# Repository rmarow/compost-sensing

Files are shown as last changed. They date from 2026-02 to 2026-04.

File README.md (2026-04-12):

# Farm Monitoring - Compost Sensing System - Complete Setup Guide
## Milk and Honey Farm at Boulder JCC

**Compost monitoring with waterproof temperature probes, ambient sensors, web dashboard, and email alerts.**

---

## 🎯 What This System Does

### Monitors Your Compost
- **DS18B20 Waterproof Probes**: Measure temperature INSIDE the compost pile
- **Automatic Alerts**: Get email when temps are too high/low
- **Web Dashboard**: View real-time data and 24-hour trends from any device
- **Data Logging**: Everything stored locally in SQLite database

### Your Alert Thresholds
- 🔥 **Compost too hot**: > 65°C (149°F)
- ❄️ **Compost too cold**: < 40°C (104°F)

---

## 📦 Requirements

### Hardware
- **Raspberry Pi 5** (with Raspberry Pi OS)
- **DS18B20 Waterproof Temperature Probes** (stainless steel, goes IN compost)
- **4.7kΩ Resistor** (required for DS18B20)
- **Screw terminal breakout board** and power supply

### Software Files

**Documentation:**
- `README.md` (this file) - Complete setup guide
- `WIRING_GUIDE.md` - Detailed sensor wiring diagrams
- `ALERT_SETUP_GUIDE.md` - Email setup instructions

**Configuration:**
- `config.py` - All settings (thresholds, GPIO pins, alerts)
- `config_local.py` - Local credentials (gitignored, not committed)
- `requirements.txt` - Python dependencies

**Core System:**
- `sensor_test.py` - Test sensors
- `database_setup.py` - Create SQLite database
- `data_collector.py` - Main monitoring script
- `dashboard.py` - Web dashboard server
- `notifications.py` - Email alert handler

**Web Interface:**
- `templates/dashboard.html` - Dashboard UI

---

## 🖨️ 3D Printed Weatherproof Case

A custom case was designed and 3D printed to house the Raspberry Pi on the compost bin. STL files are included in the `/case` folder of this repo.

### Case Features
- **Weatherproof body** — fully enclosed with a snap-on front lid; seal with silicone RTV after assembly
- **Integrated bin hook** — one-piece design, the top wall extends backward to form an arm + lip that slides over the cap board of the bin wall from the inside
- **Power hole** — top-right corner of the case (USB-C cable routes up and away)
- **Sensor holes** — two 6mm holes on the bottom wall so DS18B20 probe cables drop straight down into the compost
- **Labyrinth vents** — zigzag slots on both side walls allow airflow for passive cooling without letting water in
- **Pi standoffs** — four interior nubs match the Raspberry Pi 4 mounting hole pattern; Pi sits flush against the back wall

### Files
case-specs/case.stl                   ← main body (
case-specs/lid.stl                    ← snap-on front panel 

--- 

## 🚀 Quick Start (7 Steps)

### Step 1: Wire Your Sensors

**Read WIRING_GUIDE.md for detailed diagrams!**

**DS18B20 (Waterproof - goes IN compost):**
Note: There are 2 of these, but they share the exact same wiring config. A screw terminal breakout board is how they are attached to the Pi.
```
RED wire    → Pin 1 (3.3V)
YELLOW wire → Pin 7 (GPIO 4)
BLACK wire  → Pin 9 (Ground)
+ 4.7kΩ resistor between RED and YELLOW
```

### Step 2: Clone Repo to Raspberry Pi

```bash
# SSH into your Pi, then:
cd ~
git clone https://github.com/rmarow/compost-sensing.git
cd compost-sensing
```

Note: Instructions for connecting a Raspberry Pi to a monitor, WiFi, keyboard, and mouse can be found in the official Raspberry Pi documentation.

### Step 3: SSH and Enable 1-Wire

```bash
ssh rmarowitz@raspberrypi.local

# Enable 1-Wire interface (required for DS18B20)
sudo raspi-config
# Navigate: Interface Options → 1-Wire → Enable

# Reboot
sudo reboot
```

### Step 4: Install Dependencies

```bash
ssh rmarowitz@raspberrypi.local
cd ~/compost-sensing

# Create virtual environment
python3 -m venv venv
source venv/bin/activate

# Install packages
pip install -r requirements.txt
```

### Step 5: Test Your Sensors

```bash
python sensor_test.py
```

**You should see:**
```
✅ Found 2 DS18B20 sensor(s):
  Sensor 1 (1ft deep):  28-0000005fe1bf - Reading: 55.2°C / 131.4°F
  Sensor 2 (2ft deep):  28-0000005f6979 - Reading: 57.8°C / 136.0°F
```

**If sensors fail**, check WIRING_GUIDE.md troubleshooting section.

### Step 6: Initialize Database

```bash
python database_setup.py
```

Creates database with tables for sensor readings, alerts, and system status.

### Step 7: Start Monitoring!

**Terminal 1 - Data Collector:**
```bash
cd ~/compost-sensing
source venv/bin/activate
python data_collector.py
```

**Terminal 2 - Dashboard:**
```bash
cd ~/compost-sensing
source venv/bin/activate
python dashboard.py
```

**Access Dashboard:**
Open browser and go to: **http://raspberrypi.local:5000**

🎉 **You should see your dashboard with live sensor data!**

---

## 🔧 Configuration

Edit `config.py` to customize your system:

### Temperature Thresholds (Compost)

```python
# DS18B20 waterproof probes inside compost
DS18B20_TEMP_HIGH_THRESHOLD = 65  # Alert if > 65°C (149°F)
DS18B20_TEMP_LOW_THRESHOLD = 40   # Alert if < 40°C (104°F)
```

**Understanding Compost Temps:**
- **< 40°C**: Not actively composting
- **40-55°C**: Active mesophilic phase
- **55-65°C**: Optimal thermophilic phase (BEST!)
- **> 65°C**: Too hot, may kill beneficial bacteria

### Humidity Thresholds (Ambient)

```python
# DHT11 ambient sensor outside bin (currently disabled)
DHT11_HUMIDITY_LOW_THRESHOLD = 40   # Alert if < 40%
DHT11_HUMIDITY_HIGH_THRESHOLD = 70  # Alert if > 70%
```

### Reading Interval

```python
READING_INTERVAL = 1800  # 30 minutes (changeable in config.py)
```

### Dashboard Settings

```python
DASHBOARD_REFRESH = 60  # Auto-refresh every 60 seconds
```

---

## 🔔 Email Alerts (Optional)

Get notified immediately when thresholds are violated.

### Quick Setup

**1. Enable Email Alerts (FREE):**
```python
# In config_local.py (never committed to git)
EMAIL_ALERTS_ENABLED = True
SMTP_USERNAME = "your-email@gmail.com"
SMTP_PASSWORD = "your-gmail-app-password"  # See ALERT_SETUP_GUIDE.md
ALERT_RECIPIENTS = ["farmerbecca@boulderjcc.org"]
```

**2. Test Notifications:**
```bash
python notifications.py
```

**For complete setup instructions, see ALERT_SETUP_GUIDE.md**

### What Alerts Look Like

**Email:**
```
Subject: 🚨 Compost Alert: Bin 1 - 2ft Deep

Alert: Temperature too high: 68.5°C
Threshold: 65°C
Time: 2026-02-15 2:30 PM

[View Dashboard Button]
```

Won't spam you - 1 hour cooldown between duplicate alerts.

---

## 🤖 Run Automatically on Boot

Make the system start when your Raspberry Pi boots.

### Create systemd Services

**1. Data Collector Service:**
```bash
sudo nano /etc/systemd/system/compost-collector.service
```

Paste:
```ini
[Unit]
Description=Compost Sensing Data Collector
After=network.target

[Service]
Type=simple
User=rmarowitz
WorkingDirectory=/home/rmarowitz/compost-sensing
ExecStart=/home/rmarowitz/compost-sensing/venv/bin/python /home/rmarowitz/compost-sensing/data_collector.py
Restart=always
RestartSec=10

[Install]
WantedBy=multi-user.target
```

**2. Dashboard Service:**
```bash
sudo nano /etc/systemd/system/compost-dashboard.service
```

Paste:
```ini
[Unit]
Description=Compost Sensing Dashboard
After=network.target compost-collector.service

[Service]
Type=simple
User=rmarowitz
WorkingDirectory=/home/rmarowitz/compost-sensing
ExecStart=/home/rmarowitz/compost-sensing/venv/bin/python /home/rmarowitz/compost-sensing/dashboard.py
Restart=always
RestartSec=10

[Install]
WantedBy=multi-user.target
```

**3. Enable and Start:**
```bash
sudo systemctl daemon-reload
sudo systemctl enable compost-collector.service
sudo systemctl enable compost-dashboard.service
sudo systemctl start compost-collector.service
sudo systemctl start compost-dashboard.service
```

**4. Check Status:**
```bash
sudo systemctl status compost-collector.service
sudo systemctl status compost-dashboard.service
```

**Now it runs automatically on boot!** ✅

---

## 📊 Using the Dashboard

### What You'll See

**Main Stats Cards:**
- Active alerts (color-coded)
- Number of active sensors
- Last Google Sheets sync (if enabled)

**For Each Sensor:**
- Current temperature in °F (color-coded: green=good, red=alert)
- Temperature in °C (secondary)
- Last reading timestamp

**Combined Temperature Chart:**
- 24-hour trend for both probes on one chart
- 1ft probe in red, 2ft probe in green

**Active Alerts Section:**
- Lists all unacknowledged alerts
- Shows when alert occurred and what threshold was violated

### Accessing Dashboard

**On farm WiFi:**
```
http://raspberrypi.local:5000
```

**By IP address:**
```bash
# Find your Pi's IP
hostname -I
# Then visit: http://192.168.1.XX:5000
```

Works on any device on the same WiFi network!

---

## 🚀 Expanding Your System

### Add More DS18B20 Probes (Easy!)

Monitor multiple depths in the same bin — ALL on the same GPIO 4 pin!

```python
# In config.py
DS18B20_LOCATIONS = [
    {"id": "probe_1ft", "name": "Bin 1 - 1ft Deep", "device_id": "28-0000005fe1bf", "enabled": True},
    {"id": "probe_2ft", "name": "Bin 1 - 2ft Deep", "device_id": "28-0000005f6979", "enabled": True},
]
```

Wire them all the same way — the system auto-detects them by unique ID!

### Add DHT11 for Ambient Humidity

Each DHT11 needs its own GPIO pin:

```python
# In config.py
DHT11_SENSORS = [
    {"id": "bin1_ambient", "name": "Bin 1", "gpio_pin": 17, "enabled": True},
    {"id": "bin2_ambient", "name": "Bin 2", "gpio_pin": 27, "enabled": True},
]
```

Available GPIO pins: 17, 27, 22, 23, 24, 25

---

## 🔍 Troubleshooting

### DS18B20 Not Detected

```bash
# Check if 1-Wire is enabled
ls /sys/bus/w1/devices/
# Should see entries like: 28-0000005fe1bf

# If not found:
sudo raspi-config  # Interface Options → 1-Wire → Enable
sudo reboot

# Load modules manually
sudo modprobe w1-gpio
sudo modprobe w1-therm
```

**Check wiring:**
- RED → 3.3V (Pin 1)
- YELLOW → GPIO 4 (Pin 7)
- BLACK → Ground (Pin 9)
- **4.7kΩ resistor between RED and YELLOW**

### DHT11 Errors

DHT11 is currently disabled in config. When re-enabled, note it has a ~20-30% failure rate (normal) — the code handles this with retries.

**If all reads fail:**
```bash
# Check wiring:
# + → 5V (Pin 2)
# OUT → GPIO 17 (Pin 11)
# - → Ground (Pin 14)
# Make sure using 5V, not 3.3V!
```

### Dashboard Not Loading

```bash
# Check if running
ps aux | grep dashboard

# Restart dashboard service
sudo systemctl restart compost-dashboard.service

# Check logs
tail -f ~/compost-sensing/compost-sensing.log
```

### No Data Saving

```bash
# Check database exists
ls -lh ~/compost-sensing/compost_data.db

# Recreate if needed
python database_setup.py

# Check collector is running
sudo systemctl status compost-collector.service
```

### Alerts Not Sending

```bash
# Test notifications
python notifications.py

# Check config_local.py:
# EMAIL_ALERTS_ENABLED = True?
# SMTP credentials correct?

# See ALERT_SETUP_GUIDE.md for detailed troubleshooting
```

---

## 📁 Where Data Lives

### Database
```
/home/rmarowitz/compost-sensing/compost_data.db
```

### Logs
```
/home/rmarowitz/compost-sensing/compost-sensing.log
```

### Query Database Directly
```bash
sqlite3 ~/compost-sensing/compost_data.db

# Recent readings
SELECT * FROM sensor_readings ORDER BY timestamp DESC LIMIT 10;

# Active alerts
SELECT * FROM alerts WHERE acknowledged = 0;

# Exit
.quit
```

---

## 🎓 System Architecture

```
Physical Layer:          Data Layer:             Interface Layer:

┌──────────┐            ┌──────────┐            ┌──────────┐
│  DS18B20 │──GPIO4───→ │  SQLite  │──Query───→ │  Flask   │
│  1ft     │            │ Database │            │Dashboard │
│  Probe   │            └────┬─────┘            └────┬─────┘
├──────────┤                 │                       │
│  DS18B20 │──GPIO4───→  Local Storage          Web Browser
│  2ft     │                 │                  Any Device
│  Probe   │                 │                       │
└──────────┘            ┌────┴─────┐           ┌────┴─────┐
                        │  Alerts  │           │ Google   │
┌──────────┐            │  Check   │           │ Sheets   │
│  DHT11   │──GPIO17──→ └────┬─────┘           │(Optional)│
│ Ambient  │                 │                 └──────────┘
│(disabled)│            ┌────┴─────┐
└──────────┘            │   📧     │
                        │  Email   │
                        └──────────┘
```

---

## ✅ Success Checklist

### Hardware Setup:
- [ ] DS18B20 probes wired: RED→3.3V, YELLOW→GPIO4, BLACK→GND
- [ ] 4.7kΩ resistor between DS18B20 VCC and DATA
- [ ] Both probes connected via screw terminal breakout board
- [ ] All connections secure, no loose wires
- [ ] Raspberry Pi powered on and connected to WiFi

### Software Setup:
- [ ] 1-Wire enabled via raspi-config
- [ ] Virtual environment created
- [ ] Dependencies installed from requirements.txt
- [ ] sensor_test.py shows both sensors working
- [ ] Database created with database_setup.py
- [ ] Probe IDs and thresholds configured in config.py

### System Running:
- [ ] data_collector.py running (or as systemd service)
- [ ] dashboard.py running (or as systemd service)
- [ ] Dashboard accessible at http://raspberrypi.local:5000
- [ ] Both probes showing live data
- [ ] 24-hour combined chart displaying

### Alerts (Optional):
- [ ] Email alerts configured in config_local.py and tested
- [ ] Test alert received via notifications.py
- [ ] Cooldown period set appropriately

### Deployment:
- [ ] Probes inserted at correct depths (1ft and 2ft)
- [ ] Cables protected and secured
- [ ] System running reliably for 24+ hours
- [ ] Auto-start on boot configured

---

## 📝 Next Steps

### Phase 1b: Current Enhancements
- [ ] **Deploy to compost bin** (weatherproof enclosures)
- [ ] **Enable email alerts** (ALERT_SETUP_GUIDE.md)
- [ ] **Google Sheets integration** (hourly data sync)
- [ ] **Run 7-day reliability test**

### Phase 2: Weather Station (Coming Soon)
- Add weather sensors (temp, humidity, rainfall, wind)
- Integrate into same dashboard
- Correlate weather with compost temps

### Phase 3: Harvest Tracking (If Time Permits)
- Digital scale with Arduino
- Touchscreen UI
- Automatic tare function
- Yield tracking and reporting

---

## 🌱 Why This Setup Works

### For the Practicum:
✅ **Technical depth**: Two sensor protocols, IoT, web dev, database design
✅ **Real impact**: Actual farm problem solved with engineering
✅ **Scalable**: Easy to expand to multiple bins and sensors
✅ **Professional**: Production-ready code, proper architecture
✅ **Documented**: Clear guides for maintenance and expansion

### For the Farm:
✅ **Waterproof probes**: Measure inside the compost pile at multiple depths
✅ **Accurate data**: ±0.5°C precision for DS18B20
✅ **Remote monitoring**: Check from anywhere on farm WiFi
✅ **Alerts**: Know immediately when action needed
✅ **No ongoing costs**: Local storage + free email alerts
✅ **Expandable**: Add more bins as farm grows

### For Science:
✅ **Data-driven**: Track what actually works
✅ **Historical trends**: See seasonal patterns
✅ **Correlations**: Weather vs compost activity
✅ **Grant reporting**: Professional data visualization

---

## 🆘 Getting Help

### Check Documentation:
1. **WIRING_GUIDE.md** - Sensor connections and diagrams
2. **ALERT_SETUP_GUIDE.md** - Email setup
3. **This README** - Complete system overview

### Check Logs:
```bash
# System logs
tail -f ~/compost-sensing/compost-sensing.log

# Service logs
journalctl -u compost-collector.service -f
journalctl -u compost-dashboard.service -f
```

### Test Components:
```bash
# Test sensors
python sensor_test.py

# Test notifications
python notifications.py

# Check database
sqlite3 ~/compost-sensing/compost_data.db "SELECT COUNT(*) FROM sensor_readings;"
```

---

## 🎯 Quick Reference

### Start/Stop Services
```bash
# Start
sudo systemctl start compost-collector.service
sudo systemctl start compost-dashboard.service

# Stop
sudo systemctl stop compost-collector.service
sudo systemctl stop compost-dashboard.service

# Restart
sudo systemctl restart compost-collector.service
sudo systemctl restart compost-dashboard.service

# Status
sudo systemctl status compost-collector.service
sudo systemctl status compost-dashboard.service
```

### Manual Operation
```bash
# Terminal 1 - Data Collector
cd ~/compost-sensing
source venv/bin/activate
python data_collector.py

# Terminal 2 - Dashboard
cd ~/compost-sensing
source venv/bin/activate
python dashboard.py
```

### Important Files
```
config.py            - All settings
config_local.py      - Local credentials (gitignored)
data_collector.py    - Main monitoring loop
dashboard.py         - Web interface
notifications.py     - Alert handler
compost_data.db      - Database
compost-sensing.log  - System logs
```

---

**You're all set!** 🚀

Start with sensor wiring (WIRING_GUIDE.md), then follow the Quick Start steps above.

**Happy composting!** 🌱♻️

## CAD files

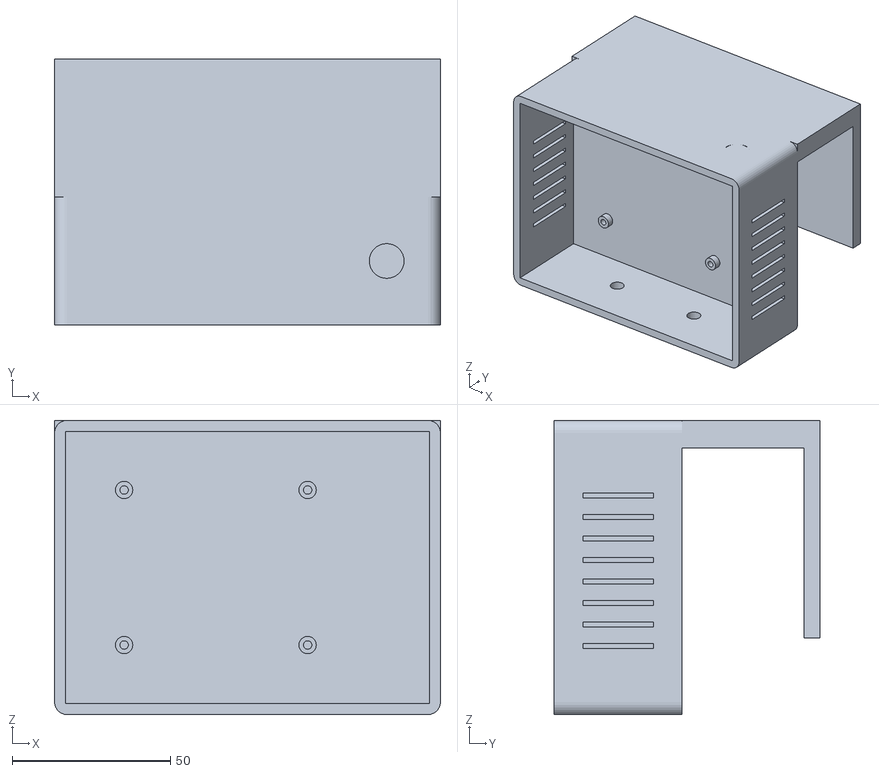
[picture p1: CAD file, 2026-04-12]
case-specs/case.stl
122.0 x 84.1 x 93.0

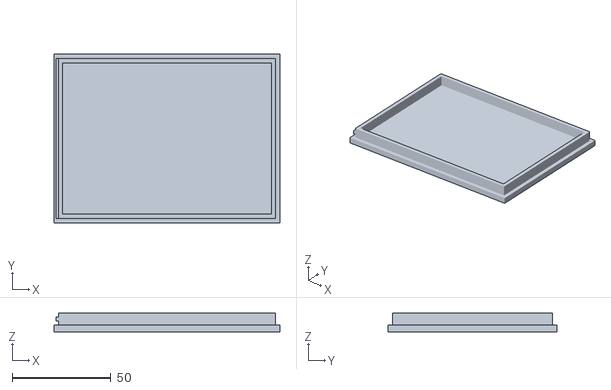
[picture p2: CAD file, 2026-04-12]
case-specs/lid.stl
114.4 x 85.4 x 9.50

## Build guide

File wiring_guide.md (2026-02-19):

# Updated Wiring Guide: DS18B20 + DHT11 Sensors
## Compost Monitoring System - Milk and Honey Farm

## 🌡️ Your New Sensor Setup

You have TWO types of sensors - perfect combination for compost monitoring!

### DS18B20 - Waterproof Temperature Probe
- **Best for**: Direct compost temperature (can go INTO the pile)
- **Measures**: Temperature only (high accuracy ±0.5°C)
- **Waterproof**: Stainless steel probe
- **Protocol**: 1-Wire (multiple sensors on one GPIO pin!)

### DHT11 - Ambient Temperature & Humidity
- **Best for**: Air temperature and humidity around the bins
- **Measures**: Temperature (±2°C) and Humidity (±5%)
- **Not waterproof**: For ambient air only
- **Protocol**: Same as DHT22 (one sensor per GPIO pin)

## 🎯 Ideal Setup

```
Compost Bin Setup:
┌─────────────────────────────┐
│    Compost Bin 1            │
│  ┌──────────────┐           │
│  │   DS18B20    │ ← Inside compost
│  │  Probe #1    │    (temperature)
│  └──────┬───────┘           │
│         │                   │
│    ┌────┴────┐              │
│    │ DHT11   │ ← Outside bin
│    │ #1      │    (air temp/humidity)
│    └─────────┘              │
└─────────────────────────────┘
```

---

## 📍 DS18B20 Waterproof Sensor Wiring

### DS18B20 Cable Colors
Most DS18B20 probes have 3 wires:
```
┌─────────────────┐
│ Stainless Steel │
│     Probe       │
└────────┬────────┘
         │ (3 wires)
    ┌────┴────┬────────┐
    │         │        │
   RED     YELLOW    BLACK
    │         │        │
   VCC      DATA      GND
  (3.3V)  (GPIO 4)  (Ground)
```

### DS18B20 to Raspberry Pi Connection
```
DS18B20                      Raspberry Pi
┌─────────┐                 ┌──────────┐
│  RED    │────────────────→│ Pin 1    │ 3.3V Power
│ YELLOW  │────────────────→│ Pin 7    │ GPIO 4 (Data)
│ BLACK   │────────────────→│ Pin 9    │ Ground
└─────────┘                 └──────────┘
```

### IMPORTANT: Pull-up Resistor Required!
DS18B20 **REQUIRES** a 4.7kΩ resistor between VCC and DATA:

```
                 ┌── 4.7kΩ Resistor ──┐
                 │                     │
DS18B20          │                     │
┌─────────┐      │                     │
│  RED    │──────┴─────────────────────┴──→ 3.3V (Pin 1)
│ YELLOW  │────────────────────────────────→ GPIO 4 (Pin 7)
│ BLACK   │────────────────────────────────→ Ground (Pin 9)
└─────────┘
```

**Note**: Some modules come with the resistor built-in. If your readings don't work, add the resistor!

---

## 📍 DHT11 Module Wiring

### DHT11 Module Pinout
Your DHT11 modules have 3 pins (module version with built-in resistor):

```
┌─────────────┐
│   DHT11     │
│   Module    │
├─────────────┤
│  -  OUT  +  │
└──┬───┬───┬──┘
   │   │   │
  GND DATA VCC
```

### DHT11 to Raspberry Pi Connection
```
DHT11 Module                 Raspberry Pi
┌─────────┐                 ┌──────────┐
│  + (VCC)│────────────────→│ Pin 2    │ 5V Power
│OUT(DATA)│────────────────→│ Pin 11   │ GPIO 17 (Data)
│  - (GND)│────────────────→│ Pin 14   │ Ground
└─────────┘                 └──────────┘
```

---

## 🔌 Complete Wiring Setup

### Pin Assignment Summary
| Sensor | Wire/Pin | Raspberry Pi Pin | GPIO # |
|---|---|---|---|
| DS18B20 | RED (VCC) | Pin 1 | 3.3V |
| DS18B20 | YELLOW (DATA) | Pin 7 | GPIO 4 |
| DS18B20 | BLACK (GND) | Pin 9 | Ground |
| DHT11 | + (VCC) | Pin 2 | 5V |
| DHT11 | OUT (DATA) | Pin 11 | GPIO 17 |
| DHT11 | - (GND) | Pin 14 | Ground |

---

## 🛠️ Step-by-Step Setup

### 1. Wire the Sensors
Follow the diagrams above

### 2. Enable 1-Wire for DS18B20
```bash
# SSH into your Pi
ssh pi@raspberrypi.local

# Enable 1-Wire interface
sudo raspi-config
# Navigate to: Interface Options > 1-Wire > Enable

# Reboot
sudo reboot

# After reboot, verify DS18B20 is detected
ls /sys/bus/w1/devices/
# Should see: 28-xxxxxxxxxxxx (your sensor ID)
```

### 3. Test DS18B20
```bash
# Read temperature directly
cat /sys/bus/w1/devices/28-*/w1_slave

# Output shows temperature in millidegrees:
# t=23187 means 23.187°C
```

### 4. Test DHT11
```bash
cd ~/farm-monitoring
source venv/bin/activate
python sensor_test.py
```

---

## 🔍 Troubleshooting

### DS18B20 Not Detected
- Check 4.7kΩ resistor is connected
- Verify wiring (RED=3.3V, YELLOW=GPIO4, BLACK=GND)
- Run `sudo modprobe w1-gpio && sudo modprobe w1-therm`

### DHT11 Checksum Errors
- Normal! DHT11 is less reliable than DHT22
- Check wiring is secure
- Make sure using 5V power (not 3.3V)

---

This sensor combo gives you:
- **Accurate compost temp** with waterproof DS18B20
- **Ambient conditions** with DHT11
- **Better reliability** - DS18B20 rarely fails
- **Scalability** - add more DS18B20s on same GPIO pin!

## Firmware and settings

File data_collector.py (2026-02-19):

#!/usr/bin/env python3
"""
Data Collector Script - Updated for DS18B20 + DHT11
Reads from waterproof temperature probes and ambient sensors
Stores data in SQLite database and handles alerts
"""

import time
import sqlite3
import glob
import os
import board
import adafruit_dht
from datetime import datetime
import logging
import sys
import config as config
from notifications import AlertNotifier

# Setup logging
logging.basicConfig(
    level=getattr(logging, config.LOG_LEVEL),
    format='%(asctime)s - %(levelname)s - %(message)s',
    handlers=[
        logging.FileHandler(config.LOG_FILE),
        logging.StreamHandler(sys.stdout)
    ]
)
logger = logging.getLogger(__name__)

class DS18B20Reader:
    """Handles DS18B20 waterproof temperature sensor reading"""
    
    def __init__(self, sensor_config):
        self.sensor_id = sensor_config['id']
        self.sensor_name = sensor_config['name']
        self.device_file = None
        self.hw_sensor_id = sensor_config.get('sensor_id', None)
        
        # Find sensor device file
        if self.hw_sensor_id:
            # Use specified sensor ID
            device_path = f"{config.W1_DEVICE_DIR}/{self.hw_sensor_id}"
            if os.path.exists(device_path):
                self.device_file = device_path + '/w1_slave'
        else:
            # Auto-detect first available sensor
            devices = glob.glob(config.W1_DEVICE_DIR + '/28-*')
            if devices:
                self.device_file = devices[0] + '/w1_slave'
                self.hw_sensor_id = os.path.basename(devices[0])
        
        if self.device_file:
            logger.info(f"Initialized DS18B20: {self.sensor_name} ({self.hw_sensor_id})")
        else:
            logger.error(f"Could not find DS18B20 sensor: {self.sensor_name}")
        
        self.last_temp_high_alert = None
        self.last_temp_low_alert = None
    
    def read_sensor(self):
        """Read temperature from DS18B20"""
        if not self.device_file:
            return {
                'temperature_c': None,
                'temperature_f': None,
                'success': False,
                'error': 'Sensor not found'
            }
        
        try:
            with open(self.device_file, 'r') as f:
                lines = f.readlines()
            
            # Check CRC
            if lines[0].strip()[-3:] != 'YES':
                raise RuntimeError("CRC check failed")
            
            # Extract temperature
            equals_pos = lines[1].find('t=')
            if equals_pos != -1:
                temp_string = lines[1][equals_pos+2:]
                temp_c = float(temp_string) / 1000.0
                temp_f = temp_c * 9.0 / 5.0 + 32.0
                
                return {
                    'temperature_c': round(temp_c, 1),
                    'temperature_f': round(temp_f, 1),
                    'success': True,
                    'error': None
                }
            else:
                raise RuntimeError("Could not parse temperature")
                
        except Exception as error:
            logger.warning(f"DS18B20 read failed ({self.sensor_name}): {error}")
            return {
                'temperature_c': None,
                'temperature_f': None,
                'success': False,
                'error': str(error)
            }
    
    def save_reading(self, reading):
        """Save DS18B20 reading to database"""
        if not reading['success']:
            return False
        
        try:
            conn = sqlite3.connect(config.DATABASE_PATH)
            cursor = conn.cursor()
            
            cursor.execute('''
                INSERT INTO sensor_readings 
                (timestamp, sensor_id, sensor_location, sensor_type,
                 temperature_c, temperature_f, humidity)
                VALUES (?, ?, ?, ?, ?, ?, ?)
            ''', (
                datetime.now(),
                self.sensor_id,
                self.sensor_name,
                'DS18B20',
                reading['temperature_c'],
                reading['temperature_f'],
                None  # DS18B20 doesn't measure humidity
            ))
            
            conn.commit()
            conn.close()
            
            logger.info(f"{self.sensor_name}: {reading['temperature_c']}°C")
            return True
            
        except Exception as error:
            logger.error(f"Error saving DS18B20 data: {error}")
            return False
    
    def check_alerts(self, reading):
        """Check DS18B20 temperature thresholds"""
        if not reading['success']:
            return
        
        now = datetime.now()
        alerts = []
        
        if reading['temperature_c'] > config.DS18B20_TEMP_HIGH_THRESHOLD:
            if self._can_send_alert(self.last_temp_high_alert):
                alerts.append({
                    'type': 'temp_high',
                    'message': f"{self.sensor_name}: Temperature too high: {reading['temperature_c']}°C",
                    'value': reading['temperature_c'],
                    'threshold': config.DS18B20_TEMP_HIGH_THRESHOLD
                })
                self.last_temp_high_alert = now
        
        if reading['temperature_c'] < config.DS18B20_TEMP_LOW_THRESHOLD:
            if self._can_send_alert(self.last_temp_low_alert):
                alerts.append({
                    'type': 'temp_low',
                    'message': f"{self.sensor_name}: Temperature too low: {reading['temperature_c']}°C",
                    'value': reading['temperature_c'],
                    'threshold': config.DS18B20_TEMP_LOW_THRESHOLD
                })
                self.last_temp_low_alert = now
        
        for alert in alerts:
            self._save_alert(alert)
            logger.warning(f"ALERT: {alert['message']}")
    
    def _can_send_alert(self, last_alert_time):
        if last_alert_time is None:
            return True
        time_since = (datetime.now() - last_alert_time).total_seconds()
        return time_since >= config.ALERT_COOLDOWN
    
    def _save_alert(self, alert):
        try:
            conn = sqlite3.connect(config.DATABASE_PATH)
            cursor = conn.cursor()
            
            cursor.execute('''
                INSERT INTO alerts 
                (timestamp, sensor_id, alert_type, message, value, threshold)
                VALUES (?, ?, ?, ?, ?, ?)
            ''', (
                datetime.now(),
                self.sensor_id,
                alert['type'],
                alert['message'],
                alert['value'],
                alert['threshold']
            ))
            
            conn.commit()
            conn.close()
            
            # Send notification if enabled
            if hasattr(self, 'notifier') and self.notifier:
                alert_data = {
                    'sensor_name': self.sensor_name,
                    'alert_type': alert['type'],
                    'message': alert['message'],
                    'value': alert['value'],
                    'threshold': alert['threshold'],
                    'timestamp': datetime.now()
                }
                self.notifier.send_alert(alert_data)
                
        except Exception as error:
            logger.error(f"Error saving alert: {error}")

class DHT11Reader:
    """Handles DHT11 ambient temperature and humidity sensor"""
    
    def __init__(self, sensor_config):
        self.sensor_id = sensor_config['id']
        self.sensor_name = sensor_config['name']
        self.gpio_pin = sensor_config['gpio_pin']
        
        pin = getattr(board, f'D{self.gpio_pin}')
        self.dht_device = adafruit_dht.DHT11(pin, use_pulseio=False)
        
        self.last_temp_high_alert = None
        self.last_temp_low_alert = None
        self.last_humidity_low_alert = None
        self.last_humidity_high_alert = None
        
        logger.info(f"Initialized DHT11: {self.sensor_name} on GPIO{self.gpio_pin}")
    
    def read_sensor(self):
        """Read temperature and humidity from DHT11 with retries"""
        for attempt in range(config.DHT11_MAX_RETRIES):
            try:
                temperature_c = self.dht_device.temperature
                humidity = self.dht_device.humidity
                
                if temperature_c is None or humidity is None:
                    if attempt < config.DHT11_MAX_RETRIES - 1:
                        time.sleep(config.DHT11_RETRY_DELAY)
                        continue
                    raise RuntimeError("Sensor returned None values")
                
                temperature_f = temperature_c * (9 / 5) + 32
                
                return {
                    'temperature_c': round(temperature_c, 1),
                    'temperature_f': round(temperature_f, 1),
                    'humidity': round(humidity, 1),
                    'success': True,
                    'error': None
                }
                
            except RuntimeError as error:
                if attempt < config.DHT11_MAX_RETRIES - 1:
                    time.sleep(config.DHT11_RETRY_DELAY)
                    continue
                logger.warning(f"DHT11 read failed ({self.sensor_name}): {error.args[0]}")
                return {
                    'temperature_c': None,
                    'temperature_f': None,
                    'humidity': None,
                    'success': False,
                    'error': str(error)
                }
        
        return {
            'temperature_c': None,
            'temperature_f': None,
            'humidity': None,
            'success': False,
            'error': 'Max retries exceeded'
        }
    
    def save_reading(self, reading):
        """Save DHT11 reading to database"""
        if not reading['success']:
            return False
        
        try:
            conn = sqlite3.connect(config.DATABASE_PATH)
            cursor = conn.cursor()
            
            cursor.execute('''
                INSERT INTO sensor_readings 
                (timestamp, sensor_id, sensor_location, sensor_type,
                 temperature_c, temperature_f, humidity)
                VALUES (?, ?, ?, ?, ?, ?, ?)
            ''', (
                datetime.now(),
                self.sensor_id,
                self.sensor_name,
                'DHT11',
                reading['temperature_c'],
                reading['temperature_f'],
                reading['humidity']
            ))
            
            conn.commit()
            conn.close()
            
            logger.info(f"{self.sensor_name}: {reading['temperature_c']}°C, {reading['humidity']}%")
            return True
            
        except Exception as error:
            logger.error(f"Error saving DHT11 data: {error}")
            return False
    
    def check_alerts(self, reading):
        """Check DHT11 thresholds"""
        if not reading['success']:
            return
        
        now = datetime.now()
        alerts = []
        
        # Temperature alerts
        if reading['temperature_c'] > config.DHT11_TEMP_HIGH_THRESHOLD:
            if self._can_send_alert(self.last_temp_high_alert):
                alerts.append({
                    'type': 'temp_high',
                    'message': f"{self.sensor_name}: Ambient temp too high: {reading['temperature_c']}°C",
                    'value': reading['temperature_c'],
                    'threshold': config.DHT11_TEMP_HIGH_THRESHOLD
                })
                self.last_temp_high_alert = now
        
        if reading['temperature_c'] < config.DHT11_TEMP_LOW_THRESHOLD:
            if self._can_send_alert(self.last_temp_low_alert):
                alerts.append({
                    'type': 'temp_low',
                    'message': f"{self.sensor_name}: Ambient temp too low: {reading['temperature_c']}°C",
                    'value': reading['temperature_c'],
                    'threshold': config.DHT11_TEMP_LOW_THRESHOLD
                })
                self.last_temp_low_alert = now
        
        # Humidity alerts
        if reading['humidity'] < config.DHT11_HUMIDITY_LOW_THRESHOLD:
            if self._can_send_alert(self.last_humidity_low_alert):
                alerts.append({
                    'type': 'humidity_low',
                    'message': f"{self.sensor_name}: Humidity too low: {reading['humidity']}%",
                    'value': reading['humidity'],
                    'threshold': config.DHT11_HUMIDITY_LOW_THRESHOLD
                })
                self.last_humidity_low_alert = now
        
        if reading['humidity'] > config.DHT11_HUMIDITY_HIGH_THRESHOLD:
            if self._can_send_alert(self.last_humidity_high_alert):
                alerts.append({
                    'type': 'humidity_high',
                    'message': f"{self.sensor_name}: Humidity too high: {reading['humidity']}%",
                    'value': reading['humidity'],
                    'threshold': config.DHT11_HUMIDITY_HIGH_THRESHOLD
                })
                self.last_humidity_high_alert = now
        
        for alert in alerts:
            self._save_alert(alert)
            logger.warning(f"ALERT: {alert['message']}")
    
    def _can_send_alert(self, last_alert_time):
        if last_alert_time is None:
            return True
        time_since = (datetime.now() - last_alert_time).total_seconds()
        return time_since >= config.ALERT_COOLDOWN
    
    def _save_alert(self, alert):
        try:
            conn = sqlite3.connect(config.DATABASE_PATH)
            cursor = conn.cursor()
            
            cursor.execute('''
                INSERT INTO alerts 
                (timestamp, sensor_id, alert_type, message, value, threshold)
                VALUES (?, ?, ?, ?, ?, ?)
            ''', (
                datetime.now(),
                self.sensor_id,
                alert['type'],
                alert['message'],
                alert['value'],
                alert['threshold']
            ))
            
            conn.commit()
            conn.close()
            
            # Send notification if enabled
            if hasattr(self, 'notifier') and self.notifier:
                alert_data = {
                    'sensor_name': self.sensor_name,
                    'alert_type': alert['type'],
                    'message': alert['message'],
                    'value': alert['value'],
                    'threshold': alert['threshold'],
                    'timestamp': datetime.now()
                }
                self.notifier.send_alert(alert_data)
                
        except Exception as error:
            logger.error(f"Error saving alert: {error}")
    
    def cleanup(self):
        try:
            self.dht_device.exit()
        except:
            pass

def main():
    """Main monitoring loop"""
    logger.info("=" * 60)
    logger.info("Starting Farm Monitoring System")
    logger.info("Updated for DS18B20 + DHT11 sensors")
    logger.info("=" * 60)
    
    # Initialize DS18B20 sensors
    ds18b20_sensors = []
    if config.DS18B20_ENABLED:
        for sensor_config in config.DS18B20_LOCATIONS:
            if sensor_config['enabled']:
                try:
                    sensor = DS18B20Reader(sensor_config)
                    if sensor.device_file:
                        ds18b20_sensors.append(sensor)
                except Exception as error:
                    logger.error(f"Failed to init DS18B20 {sensor_config['name']}: {error}")
    
    # Initialize DHT11 sensors
    dht11_sensors = []
    for sensor_config in config.DHT11_SENSORS:
        if sensor_config['enabled']:
            try:
                sensor = DHT11Reader(sensor_config)
                dht11_sensors.append(sensor)
            except Exception as error:
                logger.error(f"Failed to init DHT11 {sensor_config['name']}: {error}")
    
    total_sensors = len(ds18b20_sensors) + len(dht11_sensors)
    if total_sensors == 0:
        logger.error("No sensors initialized. Exiting.")
        sys.exit(1)
    
    logger.info(f"Initialized {len(ds18b20_sensors)} DS18B20 + {len(dht11_sensors)} DHT11 sensor(s)")
    logger.info(f"Reading interval: {config.READING_INTERVAL} seconds")
    logger.info(f"Database: {config.DATABASE_PATH}")
    
    # Initialize alert notifier
    notifier = None
    if config.EMAIL_ALERTS_ENABLED:
        notifier = AlertNotifier(config)
        logger.info("Alert notifications enabled:")
        if config.EMAIL_ALERTS_ENABLED:
            logger.info(f"  Email: {', '.join(config.ALERT_RECIPIENTS)}")

    
    # Attach notifier to all sensors
    for sensor in ds18b20_sensors + dht11_sensors:
        sensor.notifier = notifier
    
    # Main monitoring loop
    try:
        while True:
            logger.debug("Starting sensor read cycle")
            
            # Read DS18B20 sensors
            for sensor in ds18b20_sensors:
                reading = sensor.read_sensor()
                if reading['success']:
                    sensor.save_reading(reading)
                    sensor.check_alerts(reading)
            
            # Read DHT11 sensors
            for sensor in dht11_sensors:
                reading = sensor.read_sensor()
                if reading['success']:
                    sensor.save_reading(reading)
                    sensor.check_alerts(reading)
            
            # Wait for next reading
            logger.debug(f"Waiting {config.READING_INTERVAL} seconds")
            time.sleep(config.READING_INTERVAL)
            
    except KeyboardInterrupt:
        logger.info("\n\nShutdown requested by user")
    except Exception as error:
        logger.critical(f"Unexpected error: {error}", exc_info=True)
    finally:
        logger.info("Cleaning up sensors...")
        for sensor in dht11_sensors:
            sensor.cleanup()
        logger.info("Shutdown complete")

if __name__ == "__main__":
    main()

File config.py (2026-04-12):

"""
Configuration file for Farm Monitoring System
Updated for DS18B20 (waterproof temp) + DHT11 (ambient temp/humidity)
"""

# ============================================================================
# SENSOR CONFIGURATION
# ============================================================================

# Sensor reading interval (seconds)
READING_INTERVAL = 1800  # 30 minutes

# ============================================================================
# DS18B20 CONFIGURATION (Waterproof Temperature Probes)
# ============================================================================

DS18B20_ENABLED = True

# DS18B20 sensor locations (will auto-detect sensor IDs)
DS18B20_LOCATIONS = [
    {
        "id": "1ft_probe",
        "name": "Shorter probe",
        "device_id": "28-0000005fe1bf",
        "enabled": True,
    },
    {
        "id": "2ft_probe",
        "name": "Longer probe",
        "device_id": "28-0000005f6979",
        "enabled": True,
    },
]

# DS18B20 temperature thresholds (Celsius)
DS18B20_TEMP_HIGH_THRESHOLD = 65  # Alert if above 65°C
DS18B20_TEMP_LOW_THRESHOLD = 40   # Alert if below 40°C

# ============================================================================
# DHT11 CONFIGURATION (Ambient Temperature & Humidity)
# ============================================================================

DHT11_SENSORS = [
    {
        "id": "bin1_ambient",
        "name": "Bin 1 - Ambient",
        "gpio_pin": 17,  # GPIO 17 = Physical Pin 11
        "enabled": False 
    },
]

# DHT11 Temperature thresholds (Celsius)
DHT11_TEMP_HIGH_THRESHOLD = 40
DHT11_TEMP_LOW_THRESHOLD = 0

# DHT11 Humidity thresholds (percentage)
DHT11_HUMIDITY_LOW_THRESHOLD = 40
DHT11_HUMIDITY_HIGH_THRESHOLD = 70

# ============================================================================
# DATABASE CONFIGURATION
# ============================================================================

DATABASE_PATH = "/home/rmarowitz/compost-sensing/compost_data.db"
# TODO: figure out how long this should be
### NOTE: May want to change to daily or weekly averages and keep for more than a year
DATA_RETENTION_DAYS = 365

# ============================================================================
# DASHBOARD CONFIGURATION
# ============================================================================

FLASK_HOST = "0.0.0.0"
FLASK_PORT = 5000
FLASK_DEBUG = False
DASHBOARD_REFRESH = 30

# ============================================================================
# GOOGLE SHEETS INTEGRATION
# ============================================================================

GOOGLE_SHEETS_ENABLED = False
GOOGLE_CREDENTIALS_FILE = "/home/rmarowitz/compost-sensing/credentials.json"
GOOGLE_SHEET_NAME = "Milk and Honey Farm - Compost Data"
GOOGLE_SHEETS_SYNC_INTERVAL = 3600

# ============================================================================
# ALERT NOTIFICATIONS
# ============================================================================

# Enable/disable email alerts
EMAIL_ALERTS_ENABLED = True  # Set to True when configured

# Email settings (for Gmail, you'll need an app-specific password)
SMTP_SERVER = "smtp.gmail.com"
SMTP_PORT = 587
# TODO - May need to get a system email or something for milk and honey
SMTP_USERNAME = "marowitzrobyn14@gmail.com"
SMTP_PASSWORD = ""

# Alert recipients (list of email addresses)
ALERT_RECIPIENTS = [
    # "farmerbecca@boulderjcc.org",
    # "talia.edah@boulderjcc.org",
    "marowitzrobyn14@gmail.com"
]

# Alert cooldown (seconds) - prevent spam
# Won't send duplicate alerts within this period
ALERT_COOLDOWN = 3600  # 1 hour

# ============================================================================
# SMS ALERTS (Two Options)
# ============================================================================

# TODO: figure out if text is needed
#  Email-to-SMS Gateway (FREE!)
# Use your carrier's email-to-SMS gateway
# Each carrier has an email address that converts to SMS
# Format: phonenumber@carrier-gateway.com
# 
# Common carrier gateways:
# Verizon: phonenumber@vtext.com
# AT&T: phonenumber@txt.att.net  
# T-Mobile: phonenumber@tmomail.net
# Sprint: phonenumber@messaging.sprintpcs.com
# 
# Example: 3035551234@vtext.com

SMS_RECIPIENTS = [
    # Add phone numbers (Twilio) or email-to-SMS addresses (free)
    # "5551234567",  # For Twilio
    # "5551234567@vtext.com",  # For free email-to-SMS
]

# ============================================================================
# LOGGING
# ============================================================================

LOG_FILE = "/home/rmarowitz/compost-sensing/compost-sensing.log"
LOG_LEVEL = "INFO"

# ============================================================================
# ADVANCED SETTINGS
# ============================================================================

W1_DEVICE_DIR = "/sys/bus/w1/devices"
DS18B20_CONVERSION_TIME = 0.75
DHT11_MAX_RETRIES = 3
DHT11_RETRY_DELAY = 2
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

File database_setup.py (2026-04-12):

#!/usr/bin/env python3
"""
Database Setup — Milk & Honey Farm Compost Monitoring
Builds all tables from scratch. Run once before first deployment.

Tables created:
  compost_readings  — DS18B20 temperature data (two probes: shallow + deep)
  weather_readings  — Ecowitt GW1100 + WS69 weather station data
  alerts            — Threshold violation history
  system_status     — System health and lifecycle events
  sync_log          — Google Sheets sync history
"""

import sqlite3
import os
from datetime import datetime, timedelta

try:
    from config_local import *
except ImportError:
    from config import *


# ============================================================
# CREATE
# ============================================================

def create_database():
    db_dir = os.path.dirname(DATABASE_PATH)
    if db_dir and not os.path.exists(db_dir):
        os.makedirs(db_dir)

    conn = sqlite3.connect(DATABASE_PATH)
    c = conn.cursor()

    # ---- Compost temperature readings -----------------------
    # One row per probe reading. Two probes on the same 1-Wire bus:
    #   probe_id      → human label: "shallow" or "deep"
    #   probe_address → 1-Wire hardware ID (e.g. "28-0000XXXXXXXX")
    #                   lets you trace exactly which physical sensor
    #                   a reading came from even if labels change
    #   humidity      → nullable, reserved for future humidity sensor
    c.execute("""
        CREATE TABLE IF NOT EXISTS compost_readings (
            id              INTEGER PRIMARY KEY AUTOINCREMENT,
            timestamp       TEXT    NOT NULL,
            probe_id        TEXT    NOT NULL,
            probe_address   TEXT    NOT NULL,
            probe_location  TEXT    NOT NULL,
            temperature_c   REAL    NOT NULL,
            temperature_f   REAL    NOT NULL,
            humidity        REAL,
            notes           TEXT
        )
    """)
    c.execute("CREATE INDEX IF NOT EXISTS idx_compost_ts     ON compost_readings(timestamp DESC)")
    c.execute("CREATE INDEX IF NOT EXISTS idx_compost_probe  ON compost_readings(probe_id)")
    c.execute("CREATE INDEX IF NOT EXISTS idx_compost_addr   ON compost_readings(probe_address)")

    # ---- Weather station readings ---------------------------
    # Populated by weather_station.py polling the GW1100 local API.
    # All columns nullable — the gateway has built-in indoor sensors
    # even before the WS69 outdoor array arrives.
    c.execute("""
        CREATE TABLE IF NOT EXISTS weather_readings (
            id                  INTEGER PRIMARY KEY AUTOINCREMENT,
            timestamp           TEXT    NOT NULL,

            outdoor_temp_f      REAL,
            outdoor_temp_c      REAL,
            outdoor_humidity    REAL,

            wind_speed_mph      REAL,
            wind_gust_mph       REAL,
            wind_direction_deg  REAL,

            rain_rate_in_hr     REAL,
            rain_daily_in       REAL,
            rain_event_in       REAL,

            indoor_temp_f       REAL,
            indoor_humidity     REAL
        )
    """)
    c.execute("CREATE INDEX IF NOT EXISTS idx_weather_ts ON weather_readings(timestamp DESC)")

    # ---- Alerts ---------------------------------------------
    c.execute("""
        CREATE TABLE IF NOT EXISTS alerts (
            id              INTEGER PRIMARY KEY AUTOINCREMENT,
            timestamp       TEXT    NOT NULL,
            probe_id        TEXT    NOT NULL,
            alert_type      TEXT    NOT NULL,
            message         TEXT    NOT NULL,
            value           REAL    NOT NULL,
            threshold       REAL    NOT NULL,
            acknowledged    INTEGER DEFAULT 0,
            acknowledged_at TEXT
        )
    """)
    c.execute("CREATE INDEX IF NOT EXISTS idx_alerts_ts ON alerts(timestamp DESC)")

    # ---- System status --------------------------------------
    c.execute("""
        CREATE TABLE IF NOT EXISTS system_status (
            id          INTEGER PRIMARY KEY AUTOINCREMENT,
            timestamp   TEXT NOT NULL,
            status_type TEXT NOT NULL,
            message     TEXT,
            details     TEXT
        )
    """)

    # ---- Google Sheets sync log -----------------------------
    c.execute("""
        CREATE TABLE IF NOT EXISTS sync_log (
            id              INTEGER PRIMARY KEY AUTOINCREMENT,
            timestamp       TEXT NOT NULL,
            sync_type       TEXT NOT NULL,
            records_synced  INTEGER,
            status          TEXT NOT NULL,
            error_message   TEXT
        )
    """)

    # Record this setup run
    c.execute("""
        INSERT INTO system_status (timestamp, status_type, message)
        VALUES (?, 'database_init', 'Database created — two DS18B20 probes + GW1100 weather')
    """, (datetime.now().isoformat(),))

    conn.commit()
    conn.close()

    print(f"✅ Database created: {DATABASE_PATH}")
    print()
    print("Tables:")
    print("  compost_readings  — DS18B20 temps (shallow + deep probes)")
    print("  weather_readings  — GW1100 + WS69 weather station")
    print("  alerts            — threshold violations")
    print("  system_status     — system events")
    print("  sync_log          — Google Sheets sync history")


# ============================================================
# VERIFY
# ============================================================

def verify_database():
    conn = sqlite3.connect(DATABASE_PATH)
    c = conn.cursor()

    c.execute("SELECT name FROM sqlite_master WHERE type='table' ORDER BY name")
    tables = [r[0] for r in c.fetchall()]

    print()
    print(f"📊 Database: {DATABASE_PATH}")
    for table in tables:
        count = c.execute(f"SELECT COUNT(*) FROM {table}").fetchone()[0]
        print(f"   {table:<22} {count} rows")

    conn.close()


# ============================================================
# TEST DATA
# ============================================================
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

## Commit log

2026-02-13 Add configuration file for Farm Monitoring System
    This configuration file contains settings for sensor configuration, alert thresholds, database configuration, dashboard settings, Google Sheets integration, alert notifications, compost bin configura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
2026-02-15 Revise setup steps and add wiring guide reference
    Updated the README to include a wiring guide and revised steps for setup.
2026-02-15 Update configuration for DS18B20 and DHT11 sensors
2026-02-15 Add sensor test script for DS18B20 and DHT11
    This script tests DS18B20 waterproof temperature sensors and DHT11 ambient sensors, providing troubleshooting steps if sensors are not detected. It includes reading and averaging temperature and humi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
2026-02-15 Add Flask dashboard for farm monitoring system
    This file implements a Flask web application for monitoring farm sensors, including endpoints for latest readings, historical data, and system statistics.
2026-02-15 Add wiring guide for DS18B20 and DHT11 sensors
    Added detailed wiring guide for DS18B20 and DHT11 sensors including setup instructions, pin assignments, and troubleshooting tips.
2026-02-15 Create database setup script for sensor monitoring
    This script sets up a SQLite database for monitoring sensor data, including tables for sensor readings, alerts, system status, and sync logs. It also provides functions to verify the database structu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
2026-02-19 Fix email alert configuration and logging messages
    [notifications.py]
2026-04-07 update config to accomodate second sensor
2026-04-07 Refactor dashboard to include combined temperature chart
2026-04-08 Revise README for updated sensor and config details
    Updated README to reflect changes in file names and configurations for the compost monitoring system. Adjusted sensor wiring instructions and clarified alert settings.
2026-04-08 Add 3D printed weatherproof case details to README
    Added section about the 3D printed weatherproof case for Raspberry Pi, including features and file locations.
2026-04-08 rename case.stl files
    [case.stl, lid.stl]
2026-04-08 Refactor STL file paths in README
    Updated file paths for case and lid STL files.
2026-04-12 Change temperature display from Celsius to Fahrenheit
2026-04-12 Refactor dashboard HTML and update temperature units
    Updated HTML comments for clarity and changed temperature display from Celsius to Fahrenheit in the dashboard.
